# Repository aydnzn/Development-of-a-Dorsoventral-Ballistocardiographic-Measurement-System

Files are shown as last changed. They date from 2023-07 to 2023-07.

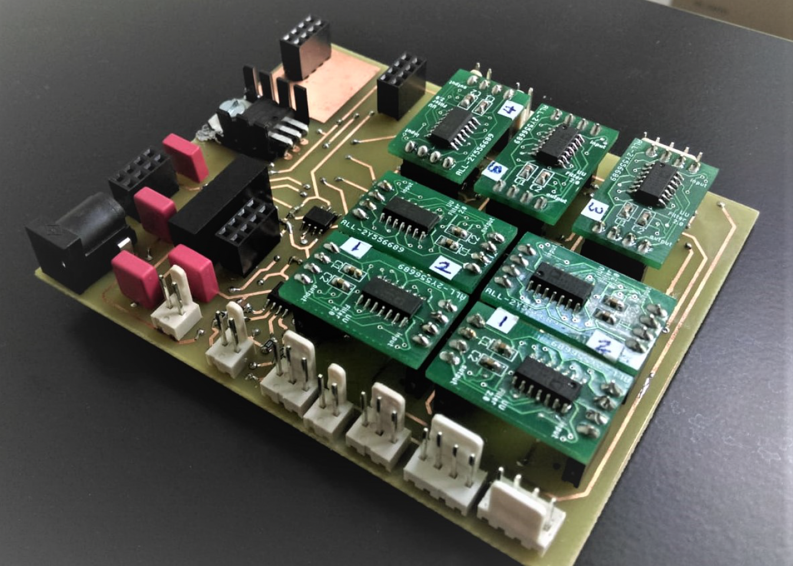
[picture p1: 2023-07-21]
photos/measurement_box_5.png

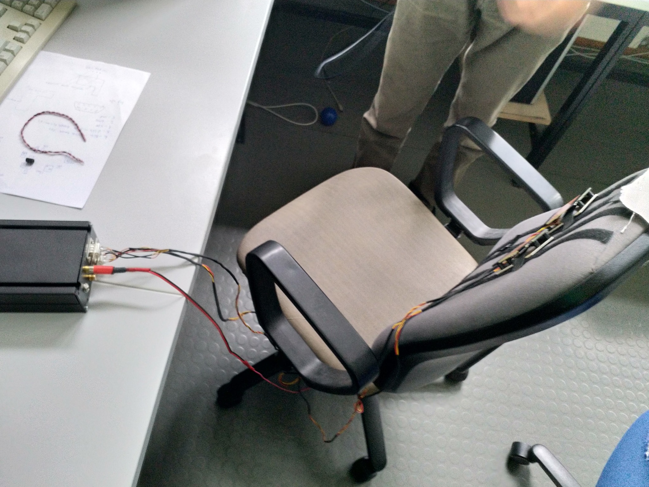
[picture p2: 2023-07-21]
photos/measurement_setup.jpeg

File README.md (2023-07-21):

# Internship Project: Development of a Dorsoventral Ballistocardiographic Measurement System

### Project Description
This project focuses on the development of a dorsoventral ballistocardiographic measurement system, specifically targeted at detecting ballistocardiographic impedance distortions in capacitive ECG. 

### Overview
This repository serves as the comprehensive archive of all the deliverables, artifacts, and insights gathered during my tenure as an intern at the [Medical Information Technology (MedIT), Helmholtz-Institute for Biomedical Engineering at RWTH Aachen University](https://www.medit.hia.rwth-aachen.de). The focus of my work centered around the design and development of capacitive ECG (cECG) and Ballistocardiography (BCG) systems, particularly exploring the nuances of human body's physiological vibrations and its impact on coupling impedance in cECG.

### Table of Contents
1. **Training_report.pdf** - This document encapsulates the cumulative learning and my detailed experience during the internship.
2. **./scripts** - This directory hosts all the Matlab scripts crafted for various analysis and computations.
3. **./photos** - A collection of photographs capturing significant moments and highlights of my internship journey.
4. **./figs** - This folder comprises of various visual representations, such as graphs and plots, created using Matlab for better understanding of problems, signals, and more.
5. **./data** - Preserved Matlab data files for future reference and use are stored here.
6. **./cnc_machine** - This section contains the necessary files required for operating the CNC machine which was instrumental in cutting the circuit boards.

### Contributors
This project was gracefully guided by [Mr. Uguz](https://ieeexplore.ieee.org/author/37086875617). I had the opportunity to develop the BCG measurement system, while my colleague, [Tuna](https://ieeexplore.ieee.org/author/37089188379), worked on the development of the impedance measurement system.

Our collaborative work, including my contributions, have been recognized and included in this [research paper](https://ieeexplore.ieee.org/document/8979354) authored by Mr. Uguz.

### License
This project is licensed under the terms of the MIT license.

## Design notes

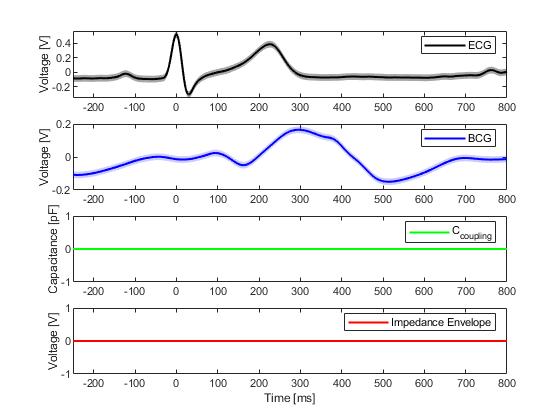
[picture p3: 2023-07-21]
figs/VM_right_2.0_rec60.jpg

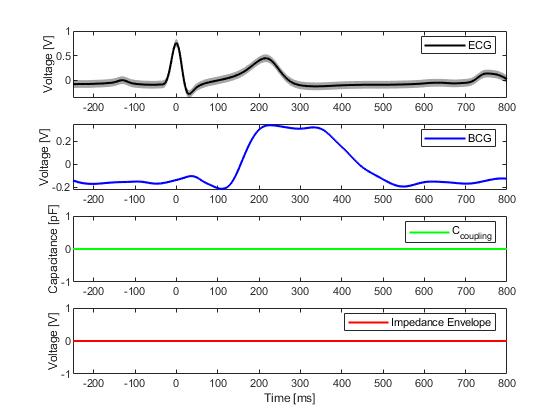
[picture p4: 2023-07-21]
figs/VM_left_6.0_rec54.jpg

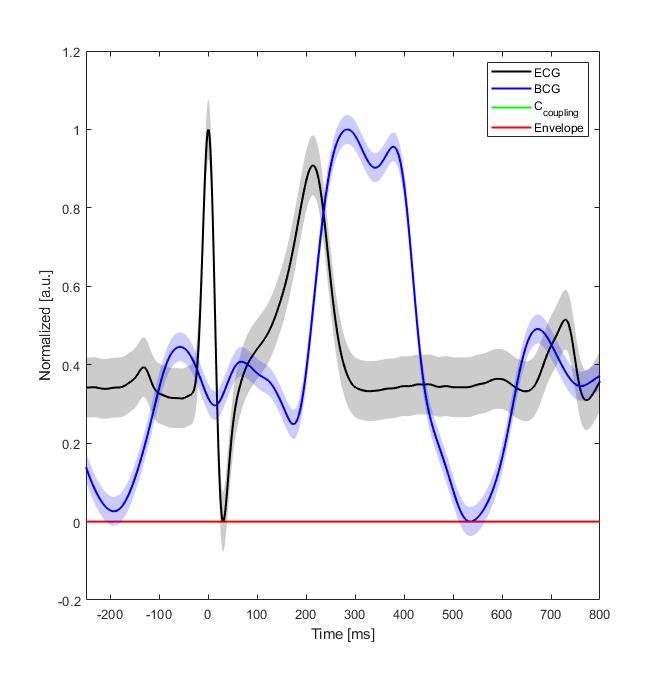
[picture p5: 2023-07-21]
figs/rec_48.jpg

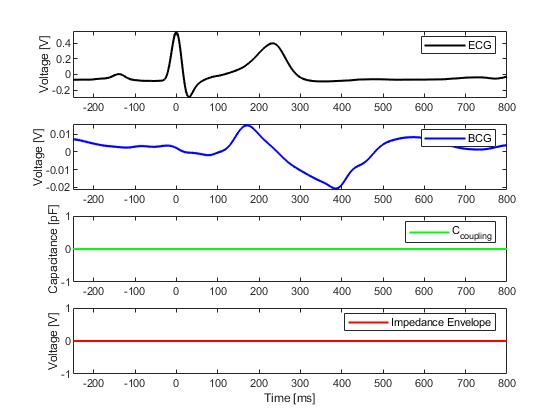
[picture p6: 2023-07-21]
figs/CM_right_1.0_rec65.jpg

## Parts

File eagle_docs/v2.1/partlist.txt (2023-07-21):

Partlist

Exported from v2.1.brd at 29.05.2019 11:04

EAGLE Version 9.1.2 Copyright (c) 1988-2018 Autodesk, Inc.

Assembly variant: 

Part     Value          Package          Library       Position (mm)         Orientation

BNC_ECG  1-227161-2     AMP_227161       con-coax      (7.4 12)              R90
BNC_RAW  1-227161-2     AMP_227161       con-coax      (7.5 48)              R90
BNC_RECT 1-227161-2     AMP_227161       con-coax      (7.5 30)              R90
BNC_REF  1-227161-2     AMP_227161       con-coax      (7.5 66)              R90
BP_RECT  FILTER_V2      MODULE_FILTER_V2 uguz_cEGG     (31 20)               R270
C1       22n            C0805            rcl           (51.6532 34.112)      MR0
C2       100n           C0805            resistor      (51.7 3.5)            MR270
C3       100n           C0805            resistor      (47.7 5.6)            MR90
C4       56n            C0805            rcl           (29.8 12.2)           MR0
C19      100n           C0805            resistor      (31.7332 35.9066)     MR0
C20      100n           C0805            resistor      (35.7104 53.9704)     MR0
D1       SD103          DIODE_SMB        eagle-ltspice (50.7 41.7)           MR0
HP       FILTER_V2      MODULE_FILTER_V2 uguz_cEGG     (31 56)               R270
IC1      OPA2107D       SO08             linear        (32.8104 44.586)      MR180
INA      AD8429         SO8              uguz_cEGG     (40.7 4)              MR90
JP_ECG                  1X02             pinhead       (23.2 3.8)            R90
JP_IMP                  1X04             pinhead       (27.0044 73.4384)     R0
JP_REF                  1X02             pinhead       (39.4356 73.8624)     R180
LP       FILTER_V2      MODULE_FILTER_V2 uguz_cEGG     (33.6 38)             R90
R1       72k            R0805            rcl           (51.7468 27.8732)     MR180
R2       1k             R0805            rcl           (52 53.2)             MR180
R3       100k           R0805            rcl           (52 48.2)             MR180
R4       82k            R0805            rcl           (31.8 16.7)           MR180
RG2      500            R0805            rcl           (31.8 4)              MR90
U$1      POWER_DUAL_12  MODULE_4X8       uguz_cEGG     (64.6424 41.005)      R270

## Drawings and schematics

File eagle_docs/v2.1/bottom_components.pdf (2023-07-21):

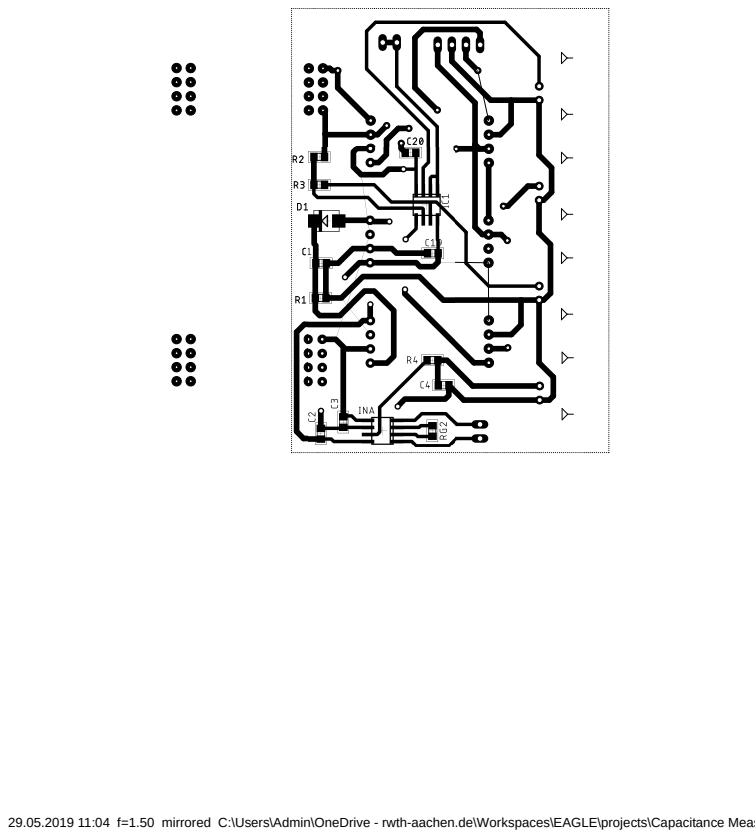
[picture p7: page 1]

29.05.2019 11:04 f=1.50 mirrored C:\Users\Admin\OneDrive - rwth-aachen.de\Workspaces\EAGLE\projects\Capacitance Measurement\Voltage_Divider\v2.1.brd

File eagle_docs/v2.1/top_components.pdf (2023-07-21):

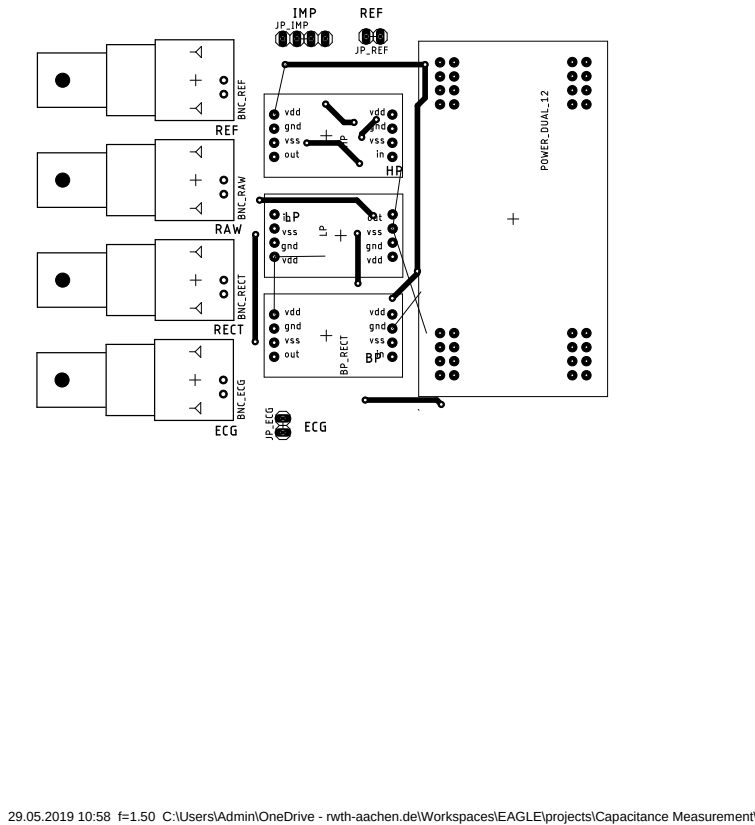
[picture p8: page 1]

29.05.2019 10:58 f=1.50 C:\Users\Admin\OneDrive - rwth-aachen.de\Workspaces\EAGLE\projects\Capacitance Measurement\Voltage_Divider\v2.1.brd

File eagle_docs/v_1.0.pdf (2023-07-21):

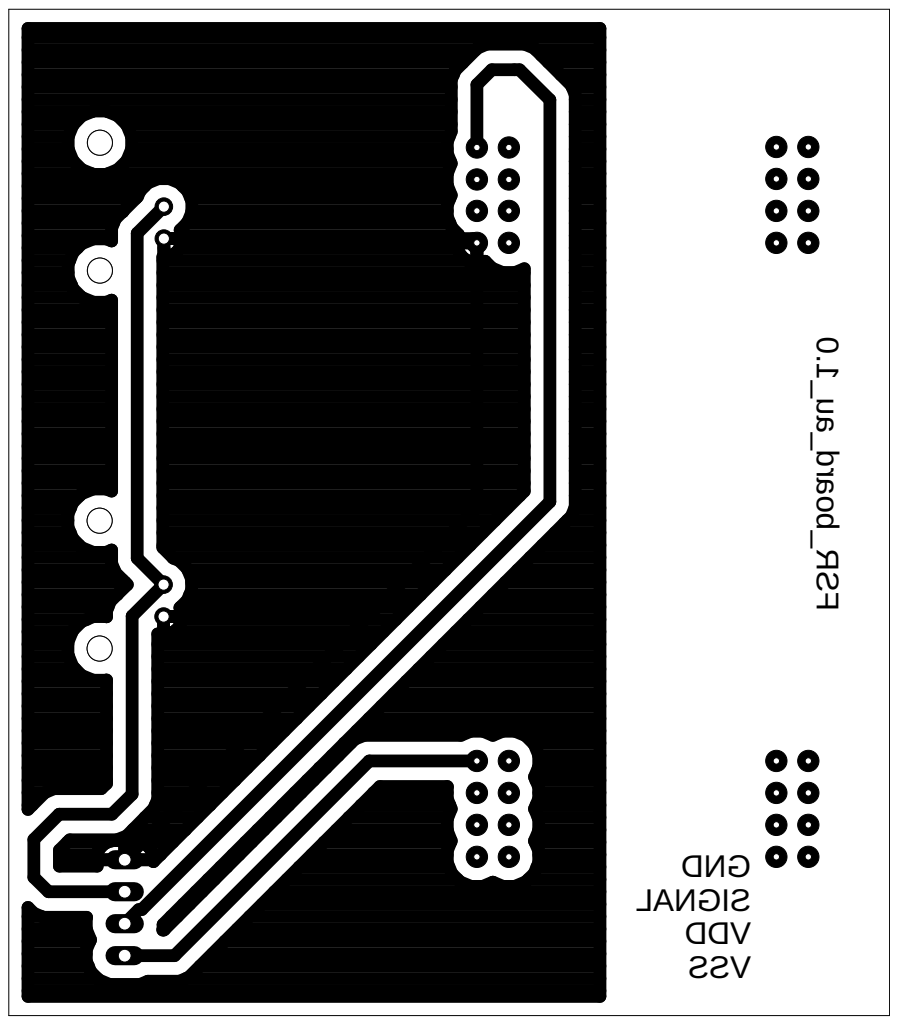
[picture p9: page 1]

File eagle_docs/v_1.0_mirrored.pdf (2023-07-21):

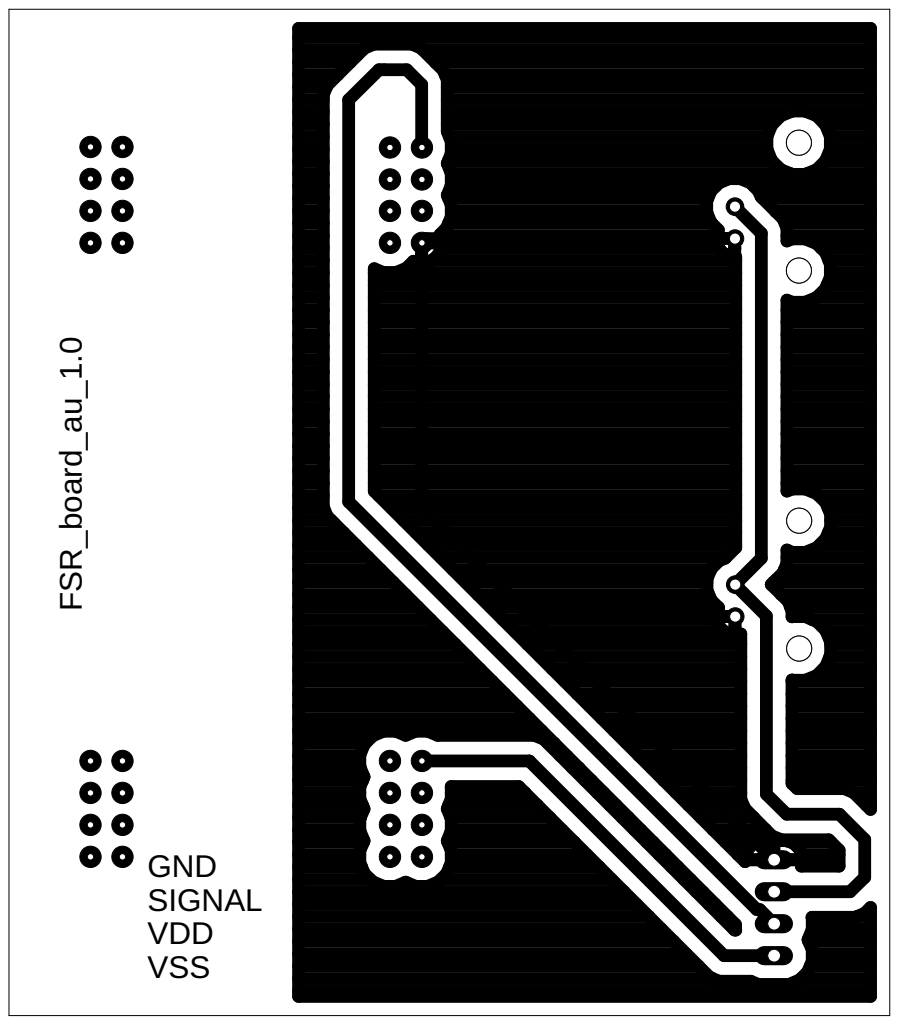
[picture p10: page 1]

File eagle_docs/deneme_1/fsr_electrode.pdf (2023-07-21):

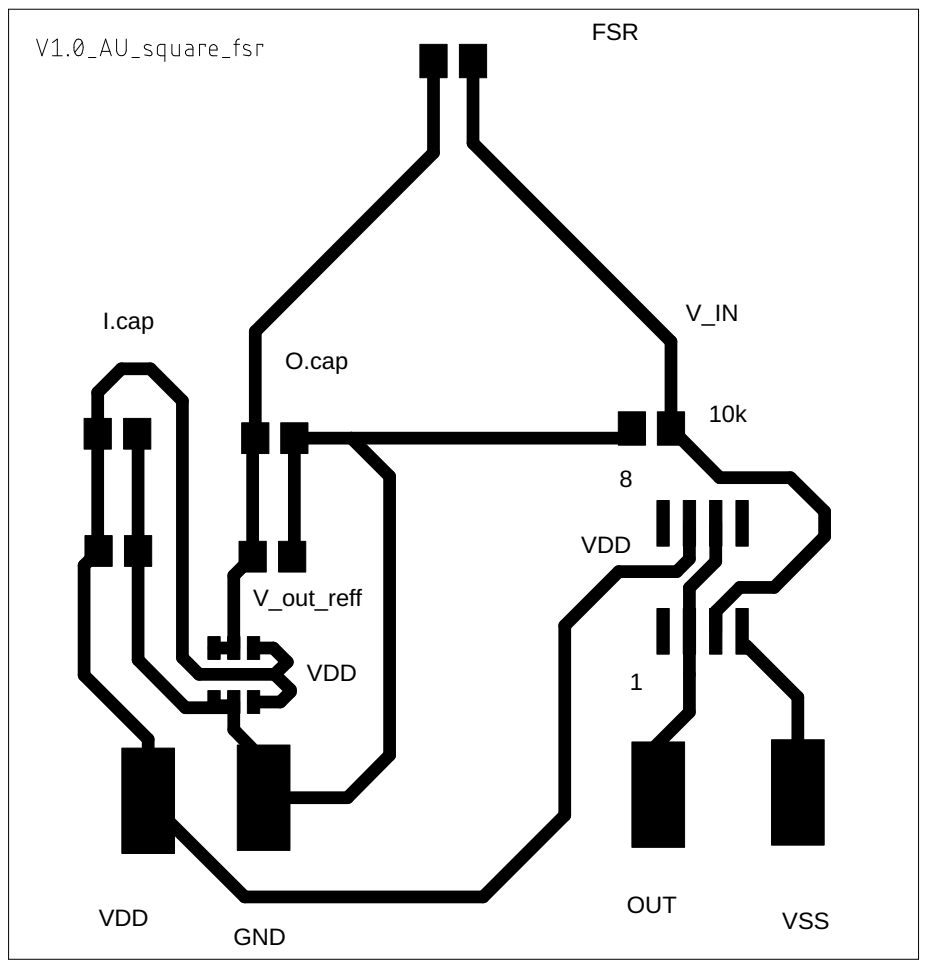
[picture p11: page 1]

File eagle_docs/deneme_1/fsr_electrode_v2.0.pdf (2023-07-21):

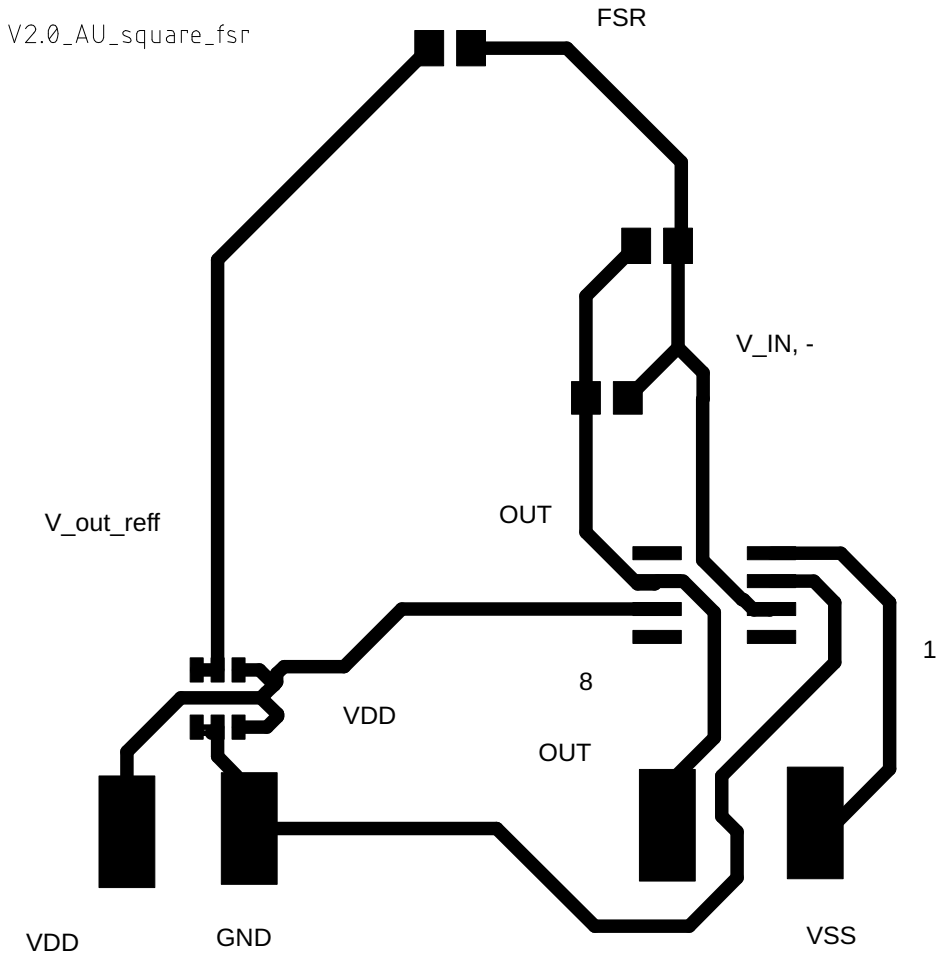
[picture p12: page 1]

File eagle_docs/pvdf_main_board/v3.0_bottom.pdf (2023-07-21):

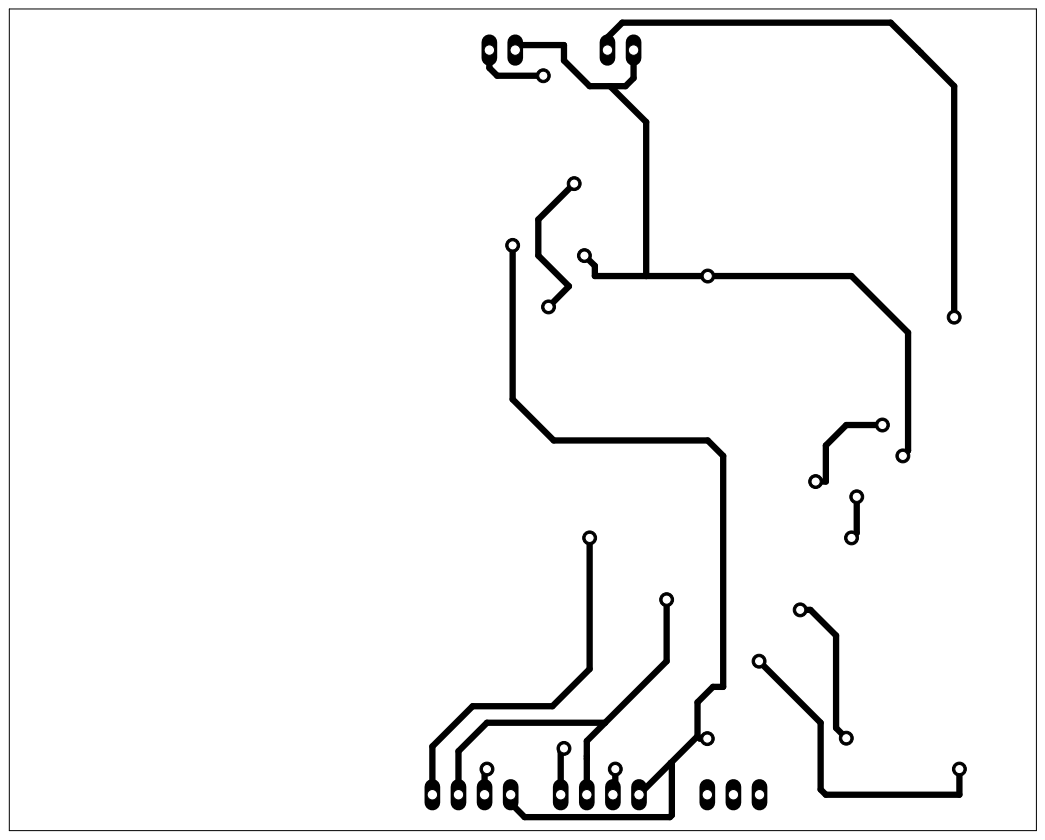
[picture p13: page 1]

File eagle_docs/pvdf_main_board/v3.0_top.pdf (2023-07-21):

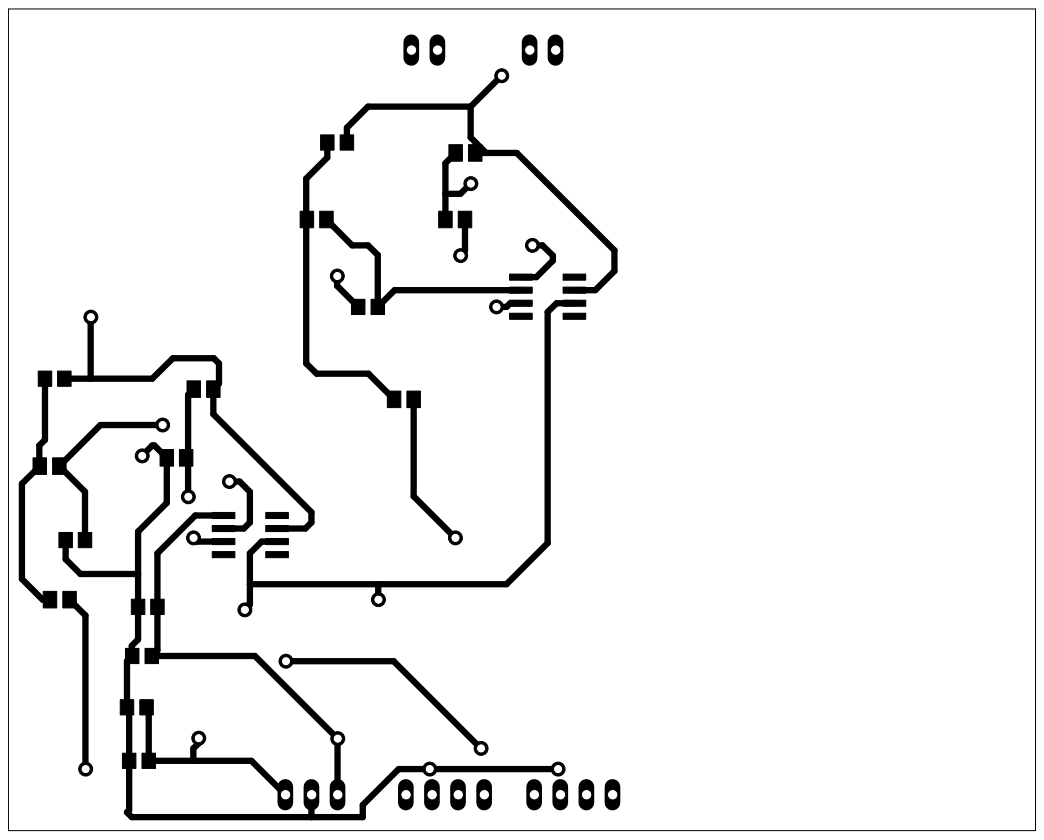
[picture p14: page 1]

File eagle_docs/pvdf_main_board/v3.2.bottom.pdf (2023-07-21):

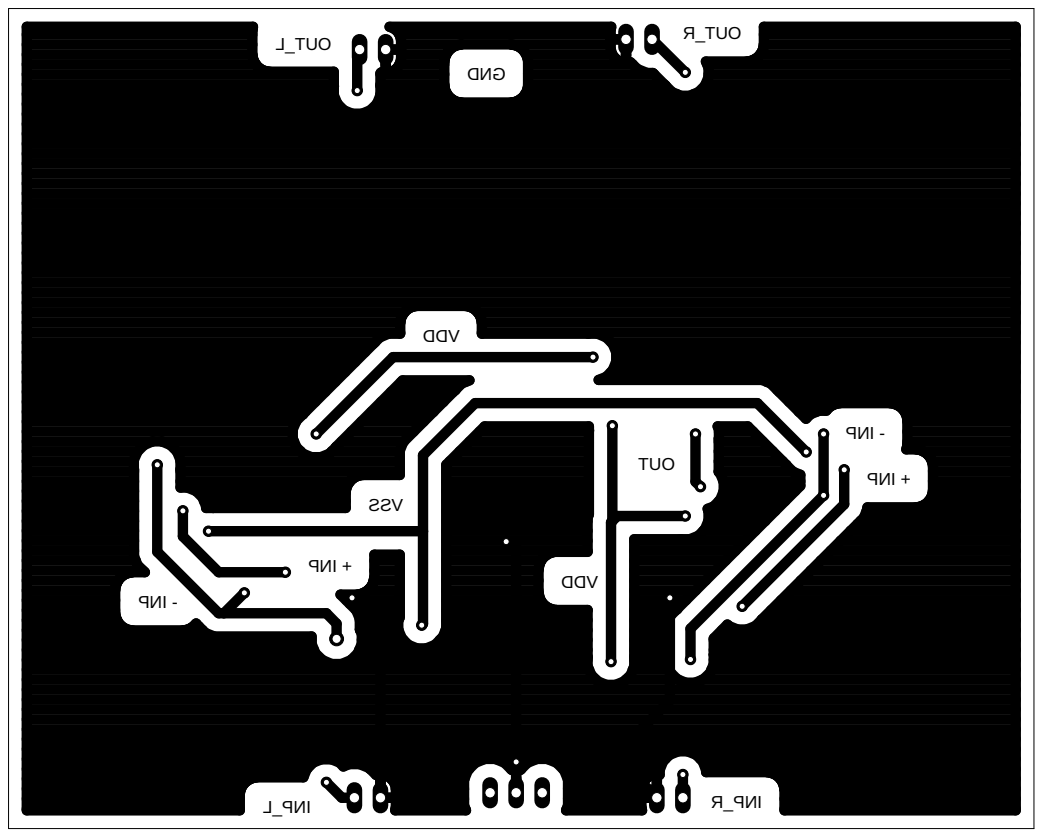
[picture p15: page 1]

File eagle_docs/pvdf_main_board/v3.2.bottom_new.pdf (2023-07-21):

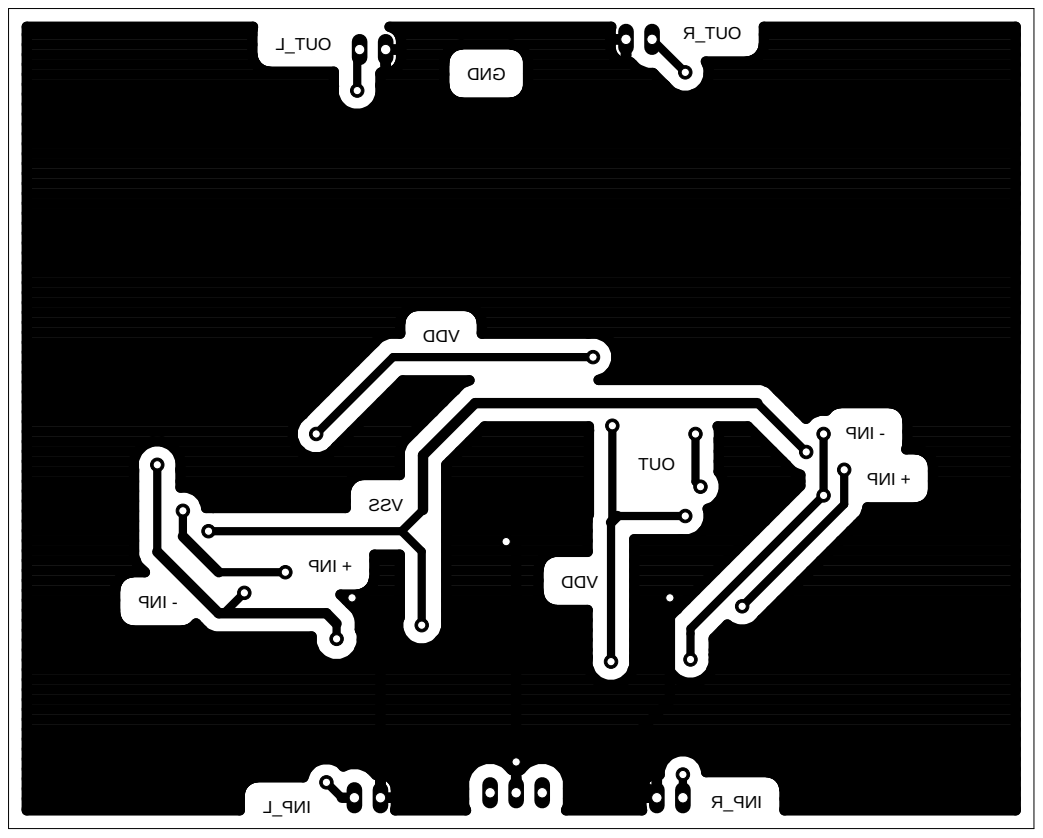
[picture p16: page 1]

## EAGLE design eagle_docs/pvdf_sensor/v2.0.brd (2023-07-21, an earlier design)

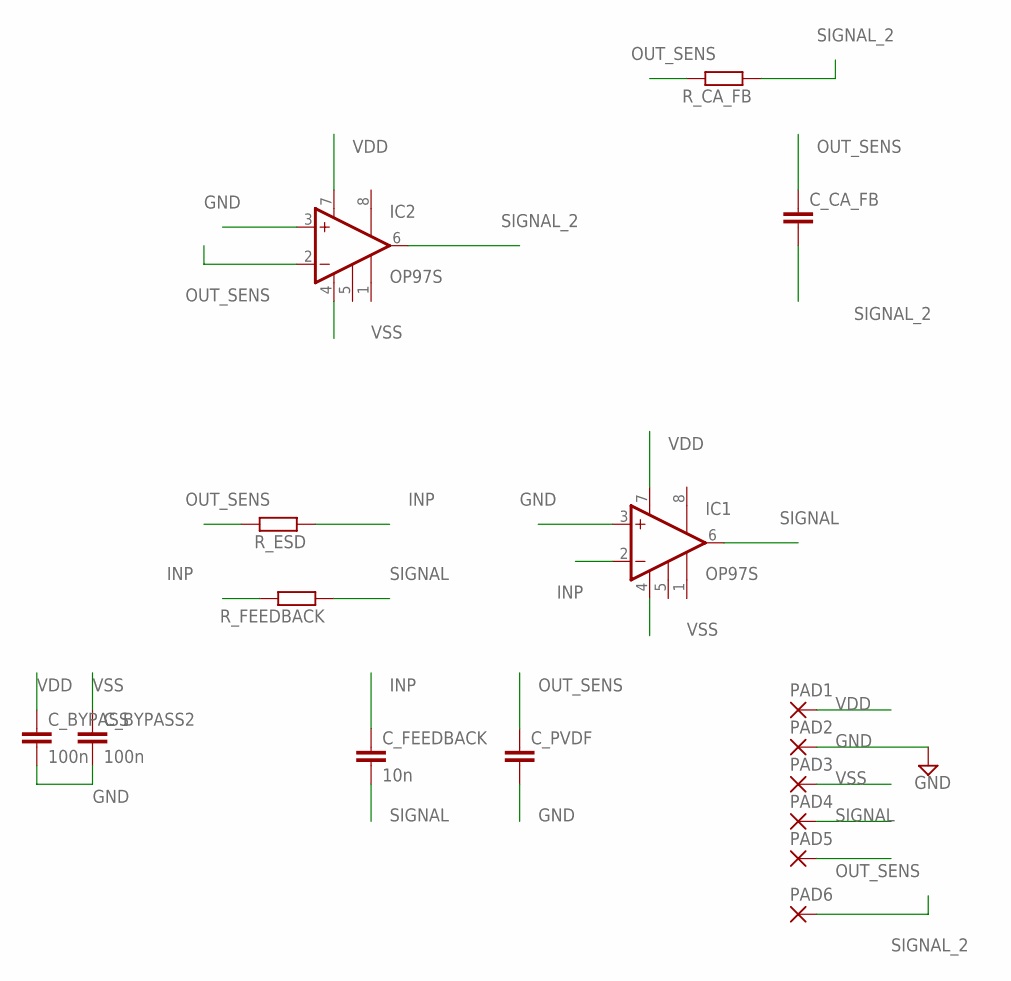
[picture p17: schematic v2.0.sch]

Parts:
C_BYPASS, C_BYPASS2: 100n; C0805
C_CA_FB: C-EUC0805; C0805
C_FEEDBACK: 10n; C0805
C_PVDF: C-EUC0805; C0805
IC1, IC2: OP97S; SO08
PAD1, PAD2, PAD3, PAD4, PAD5, PAD6: SMD5; SMD2,54-5,08
R_CA_FB: 10k; M0805
R_ESD: 5k; M0805
R_FEEDBACK: 100M; M0805

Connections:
GND: C_BYPASS.2, C_BYPASS2.2, C_PVDF.2, IC1.3 (+IN), IC2.3 (+IN), PAD2.1
INP: C_FEEDBACK.1, IC1.2 (-IN), R_ESD.1, R_FEEDBACK.2
OUT_SENS: C_CA_FB.1, C_PVDF.1, IC2.2 (-IN), PAD5.1, R_CA_FB.2, R_ESD.2
SIGNAL: C_FEEDBACK.2, IC1.6 (OUT), PAD4.1, R_FEEDBACK.1
SIGNAL_2: C_CA_FB.2, IC2.6 (OUT), PAD6.1, R_CA_FB.1
VDD: C_BYPASS.1, IC1.7 (V+), IC2.7 (V+), PAD1.1
VSS: C_BYPASS2.1, IC1.4 (V-), IC2.4 (V-), PAD3.1

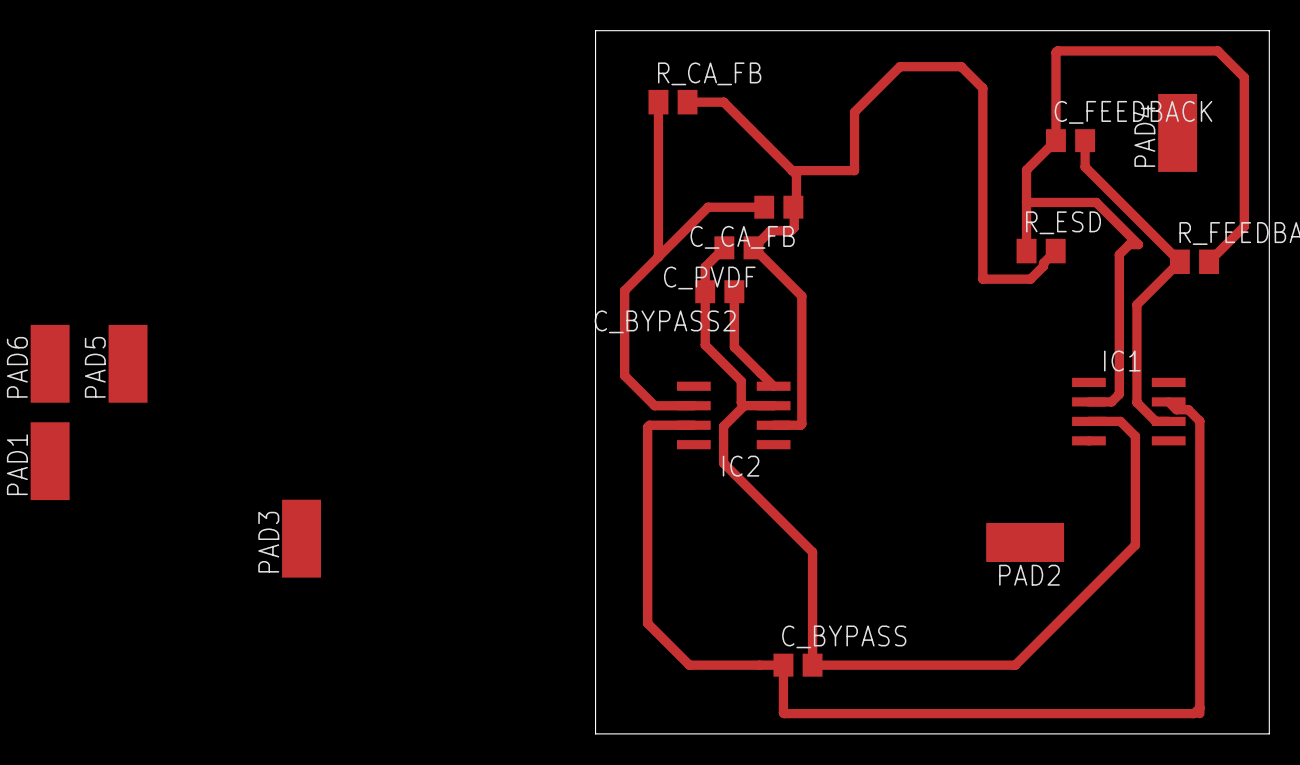
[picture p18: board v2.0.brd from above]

Board: 2 copper layers, 43.9 x 45.9 mm, 16 parts (0 on the bottom side), 7 nets.

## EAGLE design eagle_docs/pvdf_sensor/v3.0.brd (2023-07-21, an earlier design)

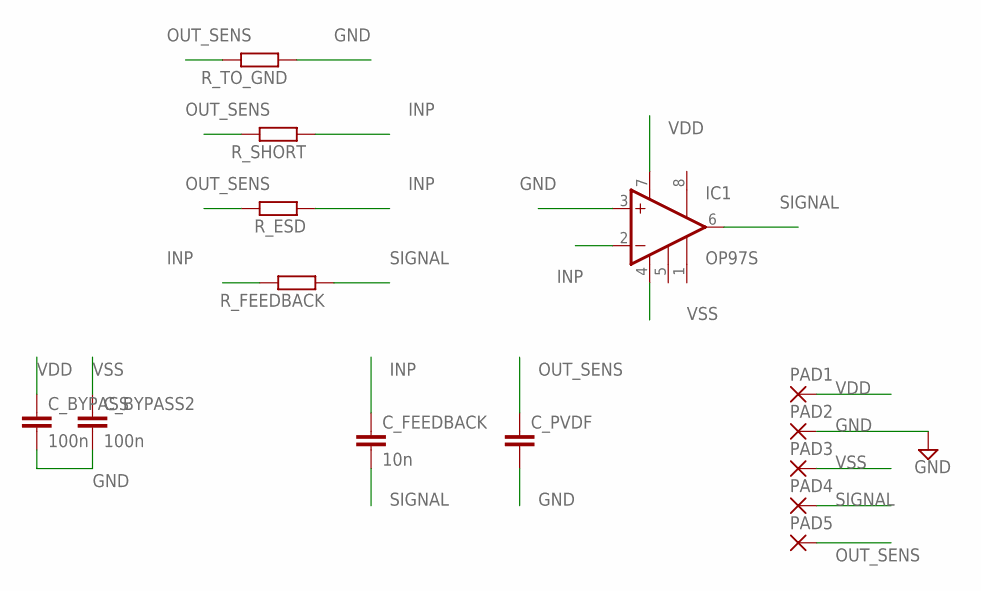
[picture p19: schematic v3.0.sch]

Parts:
C_BYPASS, C_BYPASS2: 100n; C0805
C_FEEDBACK: 10n; C0805
C_PVDF: C-EUC0805; C0805
IC1: OP97S; SO08
PAD1, PAD2, PAD3, PAD4, PAD5: SMD5; SMD2,54-5,08
R_ESD: 1M; M0805
R_FEEDBACK: 100M; M0805
R_SHORT: 1M; M0805
R_TO_GND: 1M; M0805

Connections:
GND: C_BYPASS.2, C_BYPASS2.2, C_PVDF.2, IC1.3 (+IN), PAD2.1, R_TO_GND.1
INP: C_FEEDBACK.1, IC1.2 (-IN), R_ESD.1, R_FEEDBACK.2, R_SHORT.1
OUT_SENS: C_PVDF.1, PAD5.1, R_ESD.2, R_SHORT.2, R_TO_GND.2
SIGNAL: C_FEEDBACK.2, IC1.6 (OUT), PAD4.1, R_FEEDBACK.1
VDD: C_BYPASS.1, IC1.7 (V+), PAD1.1
VSS: C_BYPASS2.1, IC1.4 (V-), PAD3.1

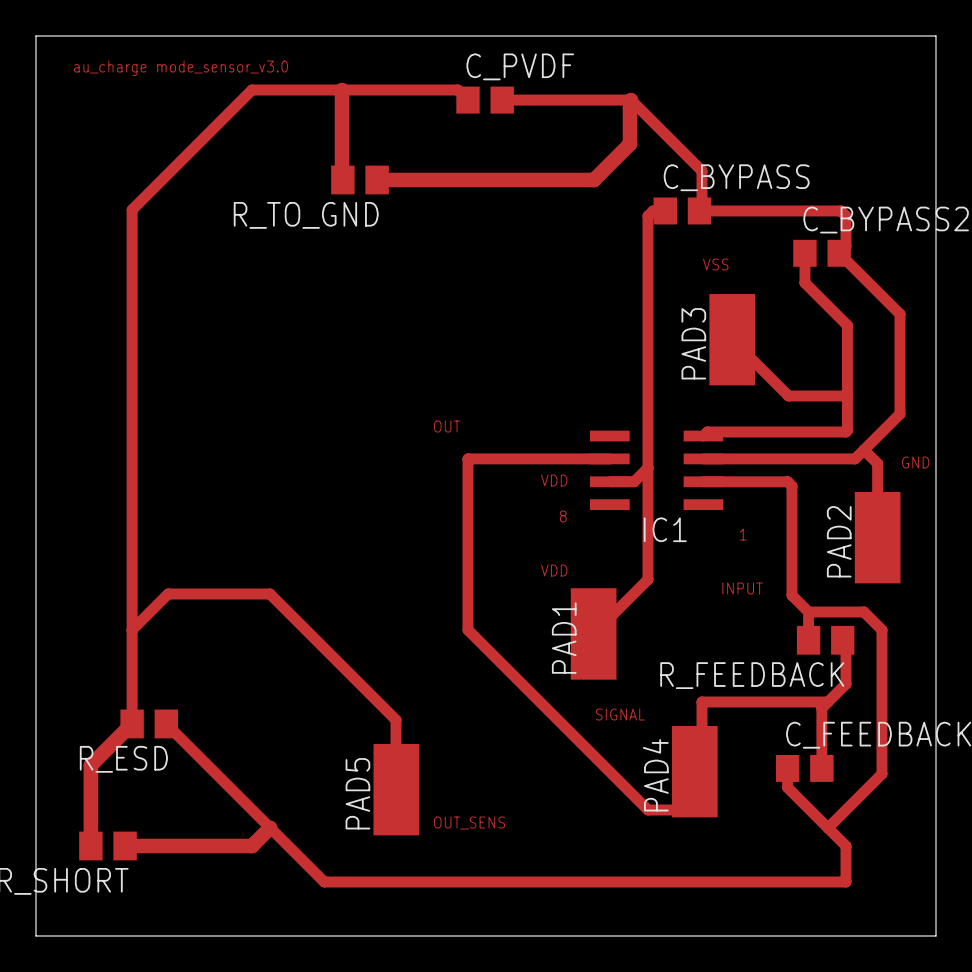
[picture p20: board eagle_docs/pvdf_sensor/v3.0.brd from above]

Board: 2 copper layers, 50.0 x 50.0 mm, 14 parts (0 on the bottom side), 6 nets.

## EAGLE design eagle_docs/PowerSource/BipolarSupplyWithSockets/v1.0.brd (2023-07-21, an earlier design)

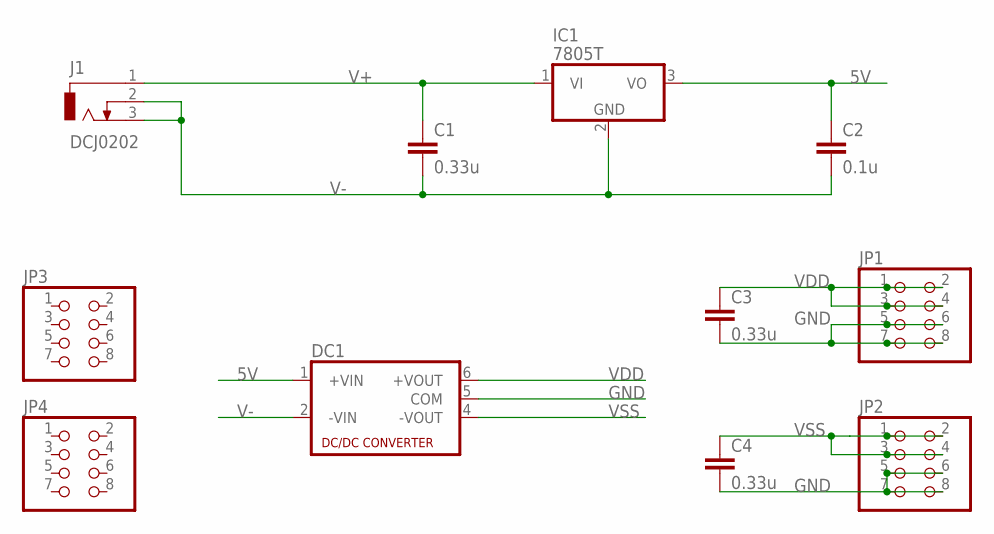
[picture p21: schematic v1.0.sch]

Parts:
C1, C3, C4: 0.33u; C050-045X075
C2: 0.1u; C050-045X075
DC1: NMA
IC1: 7805T; TO220H
J1: DCJ0202
JP1, JP2, JP3, JP4: PINHD-2X4; 2X04

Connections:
5V: C2.1, DC1.1 (+VIN), IC1.3 (VO)
GND: C3.2, C4.2, DC1.5 (COM), JP1.5, JP1.6, JP1.7, JP1.8, JP2.5, JP2.6, JP2.7, JP2.8
V+: C1.1, IC1.1 (VI), J1.1
V-: C1.2, C2.2, DC1.2 (-VIN), IC1.2 (GND), J1.2, J1.3
VDD: C3.1, DC1.6 (+VOUT), JP1.1, JP1.2, JP1.3, JP1.4
VSS: C4.1, DC1.4 (-VOUT), JP2.1, JP2.2, JP2.3, JP2.4

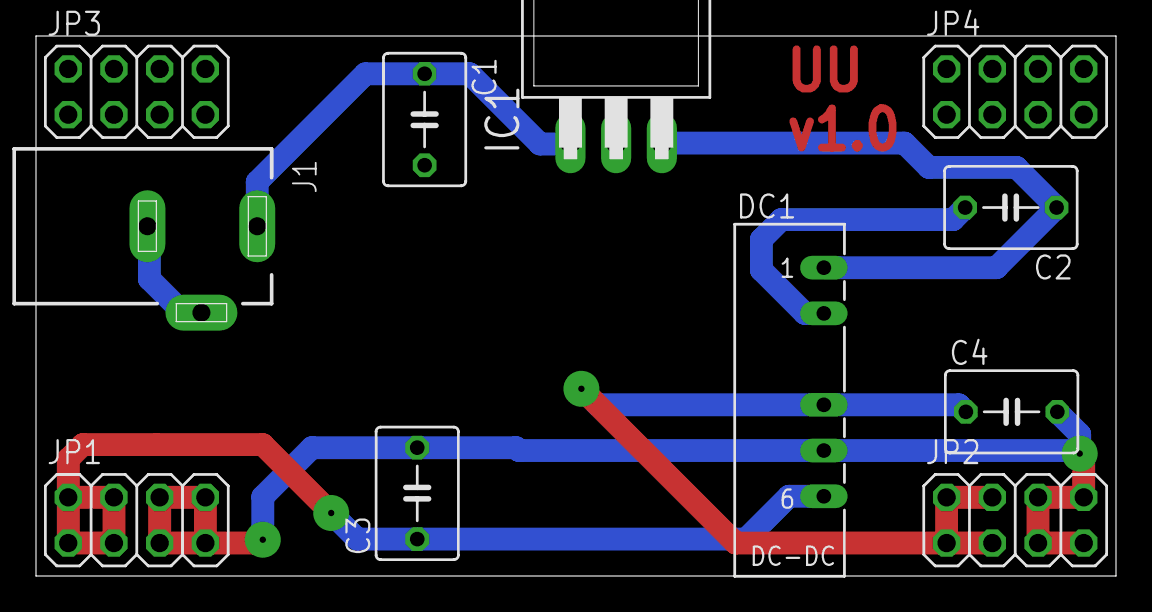
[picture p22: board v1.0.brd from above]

Board: 2 copper layers, 60.0 x 30.0 mm, 11 parts (0 on the bottom side), 6 nets.

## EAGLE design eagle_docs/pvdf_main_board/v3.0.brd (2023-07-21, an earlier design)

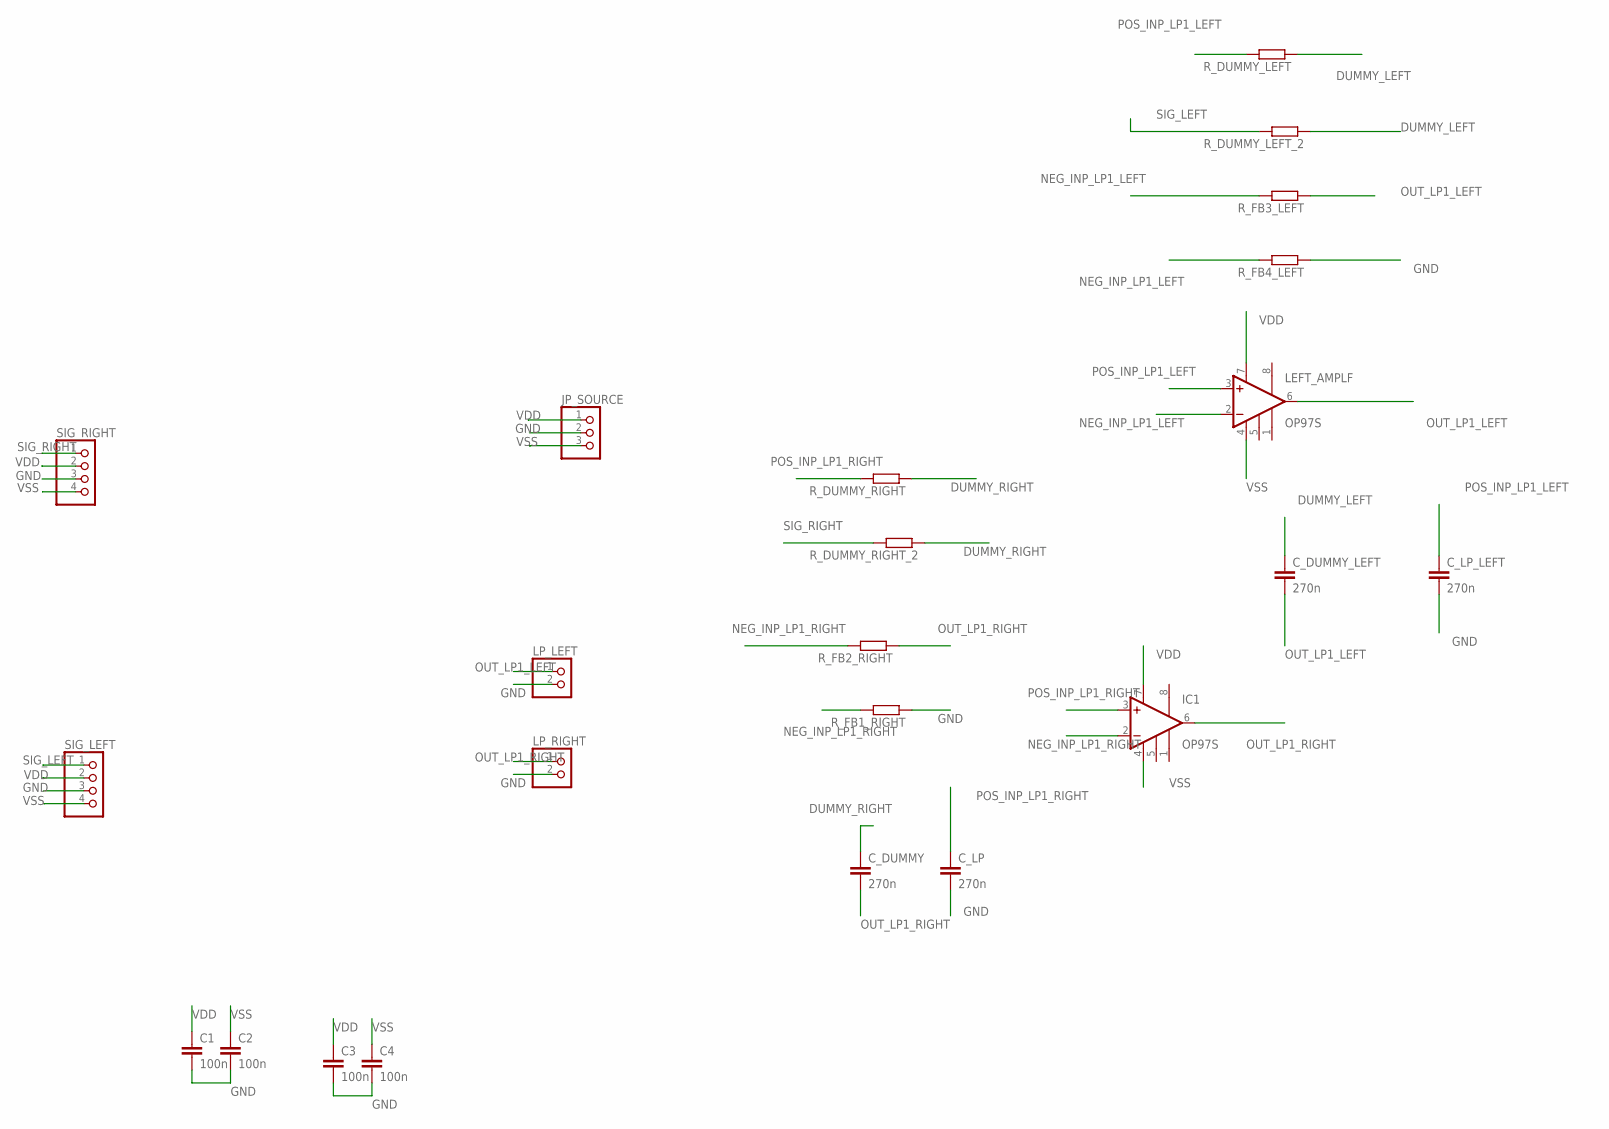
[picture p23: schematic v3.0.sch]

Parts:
C1, C2, C3, C4: 100n; C0805
C_DUMMY: 270n; C0805
C_DUMMY_LEFT: 270n; C0805
C_LP: 270n; C0805
C_LP_LEFT: 270n; C0805
IC1: OP97S; SO08
JP_SOURCE: PINHD-1X3; 1X03
LEFT_AMPLF: OP97S; SO08
LP_LEFT: PINHD-1X2; 1X02
LP_RIGHT: PINHD-1X2; 1X02
R_DUMMY_LEFT: 3.84k; M0805
R_DUMMY_LEFT_2: 3.84k; M0805
R_DUMMY_RIGHT: 3.84k; M0805
R_DUMMY_RIGHT_2: 3.84k; M0805
R_FB1_RIGHT, R_FB4_LEFT: 5.23k; M0805
R_FB2_RIGHT, R_FB3_LEFT: 256k; M0805
SIG_LEFT: PINHD-1X4; 1X04
SIG_RIGHT: PINHD-1X4; 1X04

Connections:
DUMMY_LEFT: C_DUMMY_LEFT.1, R_DUMMY_LEFT.1, R_DUMMY_LEFT_2.1
DUMMY_RIGHT: C_DUMMY.1, R_DUMMY_RIGHT.1, R_DUMMY_RIGHT_2.1
GND: C1.2, C2.2, C3.2, C4.2, C_LP.2, C_LP_LEFT.2, JP_SOURCE.2, LP_LEFT.2, LP_RIGHT.2, R_FB1_RIGHT.1, R_FB4_LEFT.1, SIG_LEFT.3, SIG_RIGHT.3
NEG_INP_LP1_LEFT: LEFT_AMPLF.2 (-IN), R_FB3_LEFT.2, R_FB4_LEFT.2
NEG_INP_LP1_RIGHT: IC1.2 (-IN), R_FB1_RIGHT.2, R_FB2_RIGHT.2
OUT_LP1_LEFT: C_DUMMY_LEFT.2, LEFT_AMPLF.6 (OUT), LP_LEFT.1, R_FB3_LEFT.1
OUT_LP1_RIGHT: C_DUMMY.2, IC1.6 (OUT), LP_RIGHT.1, R_FB2_RIGHT.1
POS_INP_LP1_LEFT: C_LP_LEFT.1, LEFT_AMPLF.3 (+IN), R_DUMMY_LEFT.2
POS_INP_LP1_RIGHT: C_LP.1, IC1.3 (+IN), R_DUMMY_RIGHT.2
SIG_LEFT: R_DUMMY_LEFT_2.2, SIG_LEFT.1
SIG_RIGHT: R_DUMMY_RIGHT_2.2, SIG_RIGHT.1
VDD: C1.1, C3.1, IC1.7 (V+), JP_SOURCE.1, LEFT_AMPLF.7 (V+), SIG_LEFT.2, SIG_RIGHT.2
VSS: C2.1, C4.1, IC1.4 (V-), JP_SOURCE.3, LEFT_AMPLF.4 (V-), SIG_LEFT.4, SIG_RIGHT.4

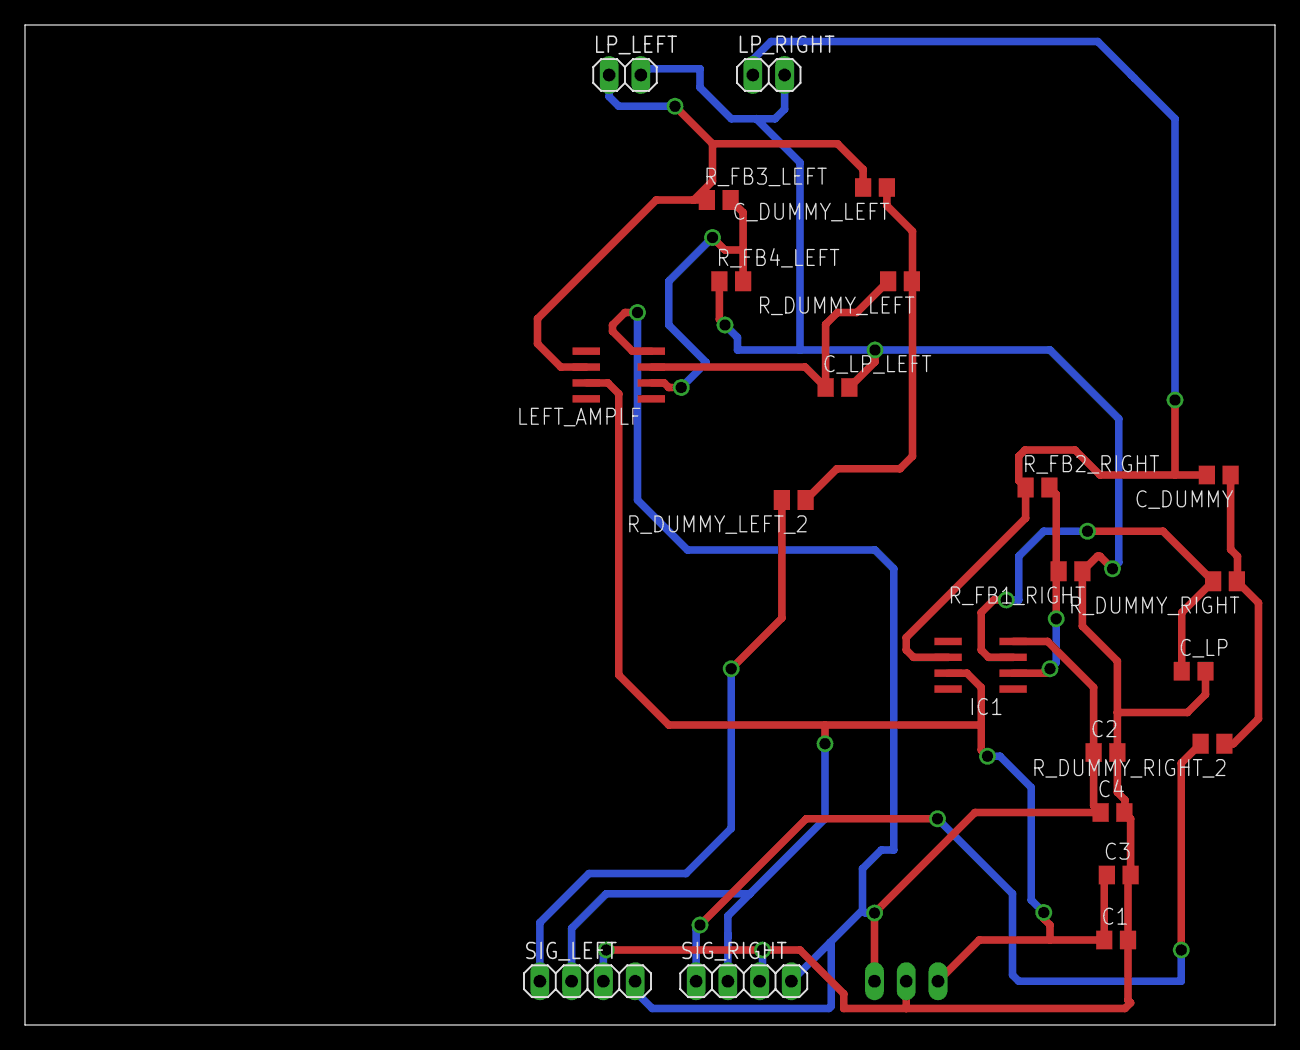
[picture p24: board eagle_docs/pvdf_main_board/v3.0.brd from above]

Board: 2 copper layers, 100.0 x 80.0 mm, 23 parts (1 on the bottom side), 13 nets.

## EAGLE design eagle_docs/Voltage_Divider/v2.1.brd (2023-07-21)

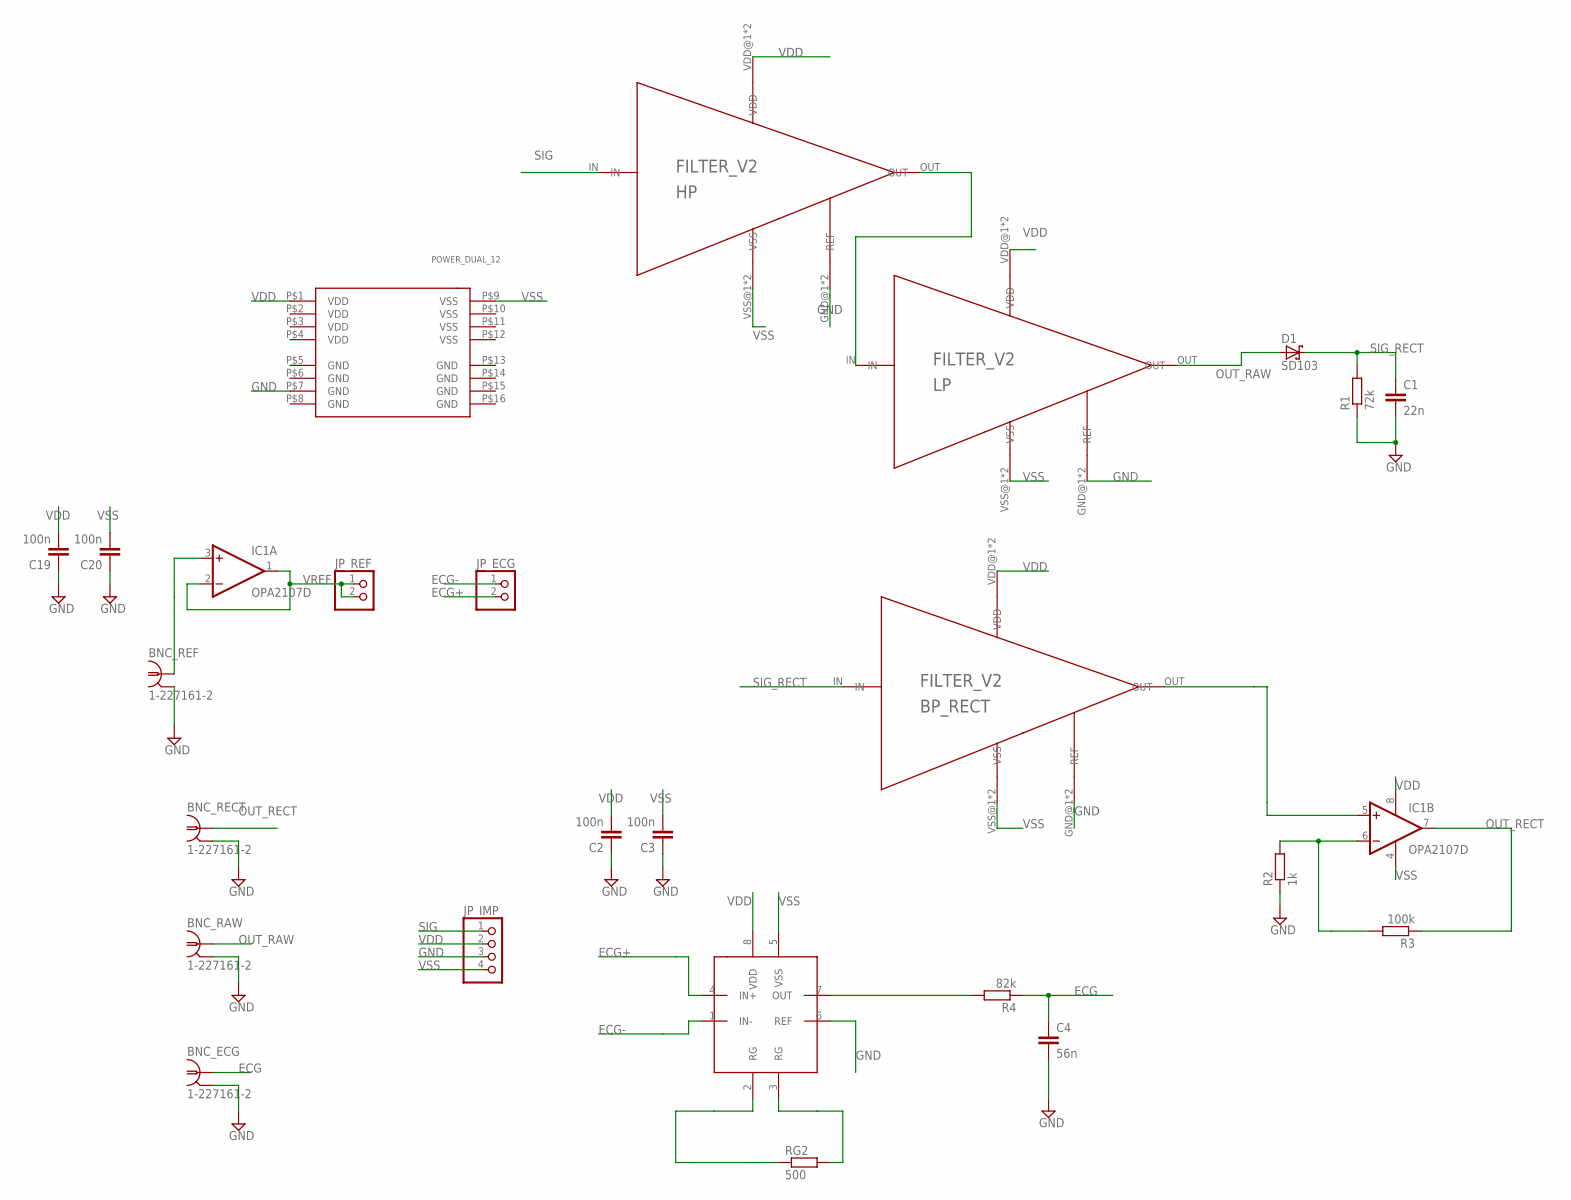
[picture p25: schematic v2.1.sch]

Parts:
BNC_ECG: 1-227161-2; AMP_227161
BNC_RAW: 1-227161-2; AMP_227161
BNC_RECT: 1-227161-2; AMP_227161
BNC_REF: 1-227161-2; AMP_227161
BP_RECT: FILTER_V2; MODULE_FILTER_V2
C1: 22n; C0805
C2, C3, C19, C20: 100n; C0805
C4: 56n; C0805
D1: SD103; DIODE_SMB
HP: FILTER_V2; MODULE_FILTER_V2
IC1: OPA2107D; SO08
INA: AD8429; SO8
JP_ECG: PINHD-1X2; 1X02
JP_IMP: PINHD-1X4; 1X04
JP_REF: PINHD-1X2; 1X02
LP: FILTER_V2; MODULE_FILTER_V2
R1: 72k; R0805
R2: 1k; R0805
R3: 100k; R0805
R4: 82k; R0805
RG2: 500; R0805
U$1: POWER_DUAL_12; MODULE_4X8

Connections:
ECG: BNC_ECG.1, C4.1, R4.1
ECG+: INA.4 (IN+), JP_ECG.2
ECG-: INA.1 (IN-), JP_ECG.1
GND: BNC_ECG.2, BNC_RAW.2, BNC_RECT.2, BNC_REF.2, BP_RECT.GND@1 (REF), BP_RECT.GND@2 (REF), C1.2, C2.1, C3.1, C4.2, C19.1, C20.1, HP.GND@1 (REF), HP.GND@2 (REF), INA.6 (REF), JP_IMP.3, LP.GND@1 (REF), LP.GND@2 (REF), R1.1, R2.1, U$1.P$7 (GND)
unnamed: IC1.6 (-IN), R2.2, R3.2
unnamed: BP_RECT.OUT, IC1.5 (+IN)
unnamed: INA.7 (OUT), R4.2
unnamed: HP.OUT, LP.IN
unnamed: BNC_REF.1, IC1.3 (+IN)
unnamed: INA.2 (RG), RG2.1
unnamed: INA.3 (RG), RG2.2
OUT_RAW: BNC_RAW.1, D1.A (C), LP.OUT
OUT_RECT: BNC_RECT.1, IC1.7 (OUT), R3.1
SIG: HP.IN, JP_IMP.1
SIG_RECT: BP_RECT.IN, C1.1, D1.C (A), R1.2
VDD: BP_RECT.VDD@1 (VDD), BP_RECT.VDD@2 (VDD), C2.2, C19.2, HP.VDD@1 (VDD), HP.VDD@2 (VDD), IC1.8 (V+), INA.8 (VDD), JP_IMP.2, LP.VDD@1 (VDD), LP.VDD@2 (VDD), U$1.P$1 (VDD)
VREF: IC1.1 (OUT), IC1.2 (-IN), JP_REF.1, JP_REF.2
VSS: BP_RECT.VSS@1 (VSS), BP_RECT.VSS@2 (VSS), C3.2, C20.2, HP.VSS@1 (VSS), HP.VSS@2 (VSS), IC1.4 (V-), INA.5 (VSS), JP_IMP.4, LP.VSS@1 (VSS), LP.VSS@2 (VSS), U$1.P$9 (VSS)

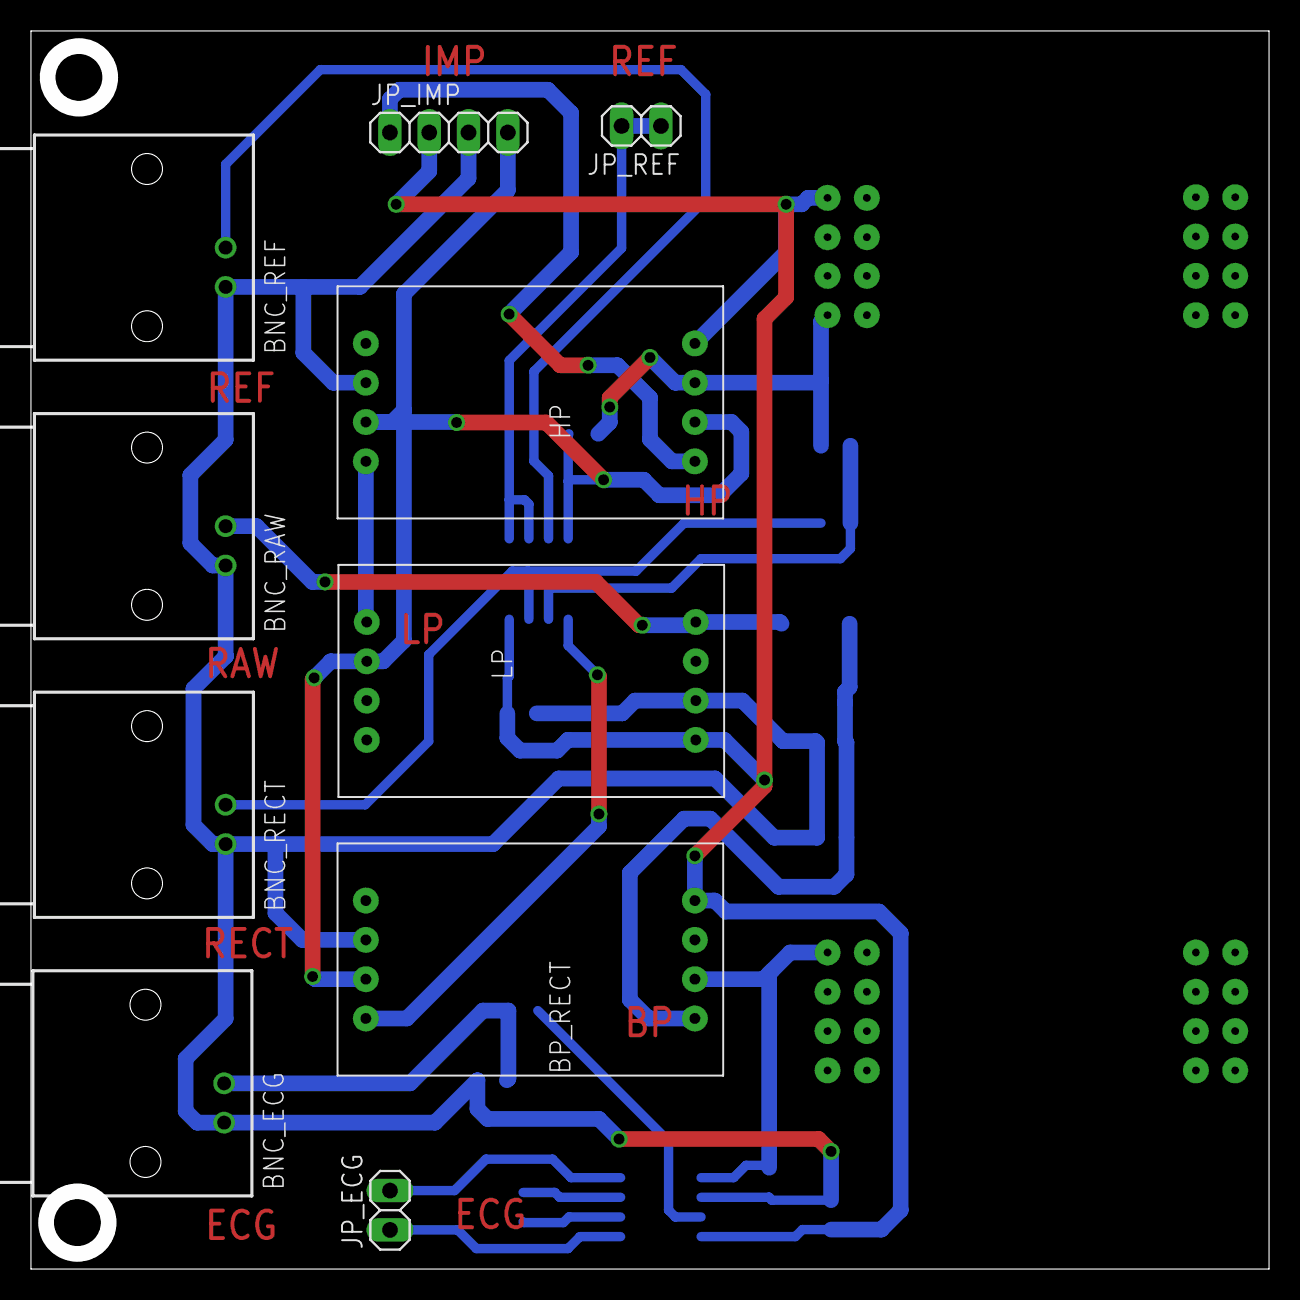
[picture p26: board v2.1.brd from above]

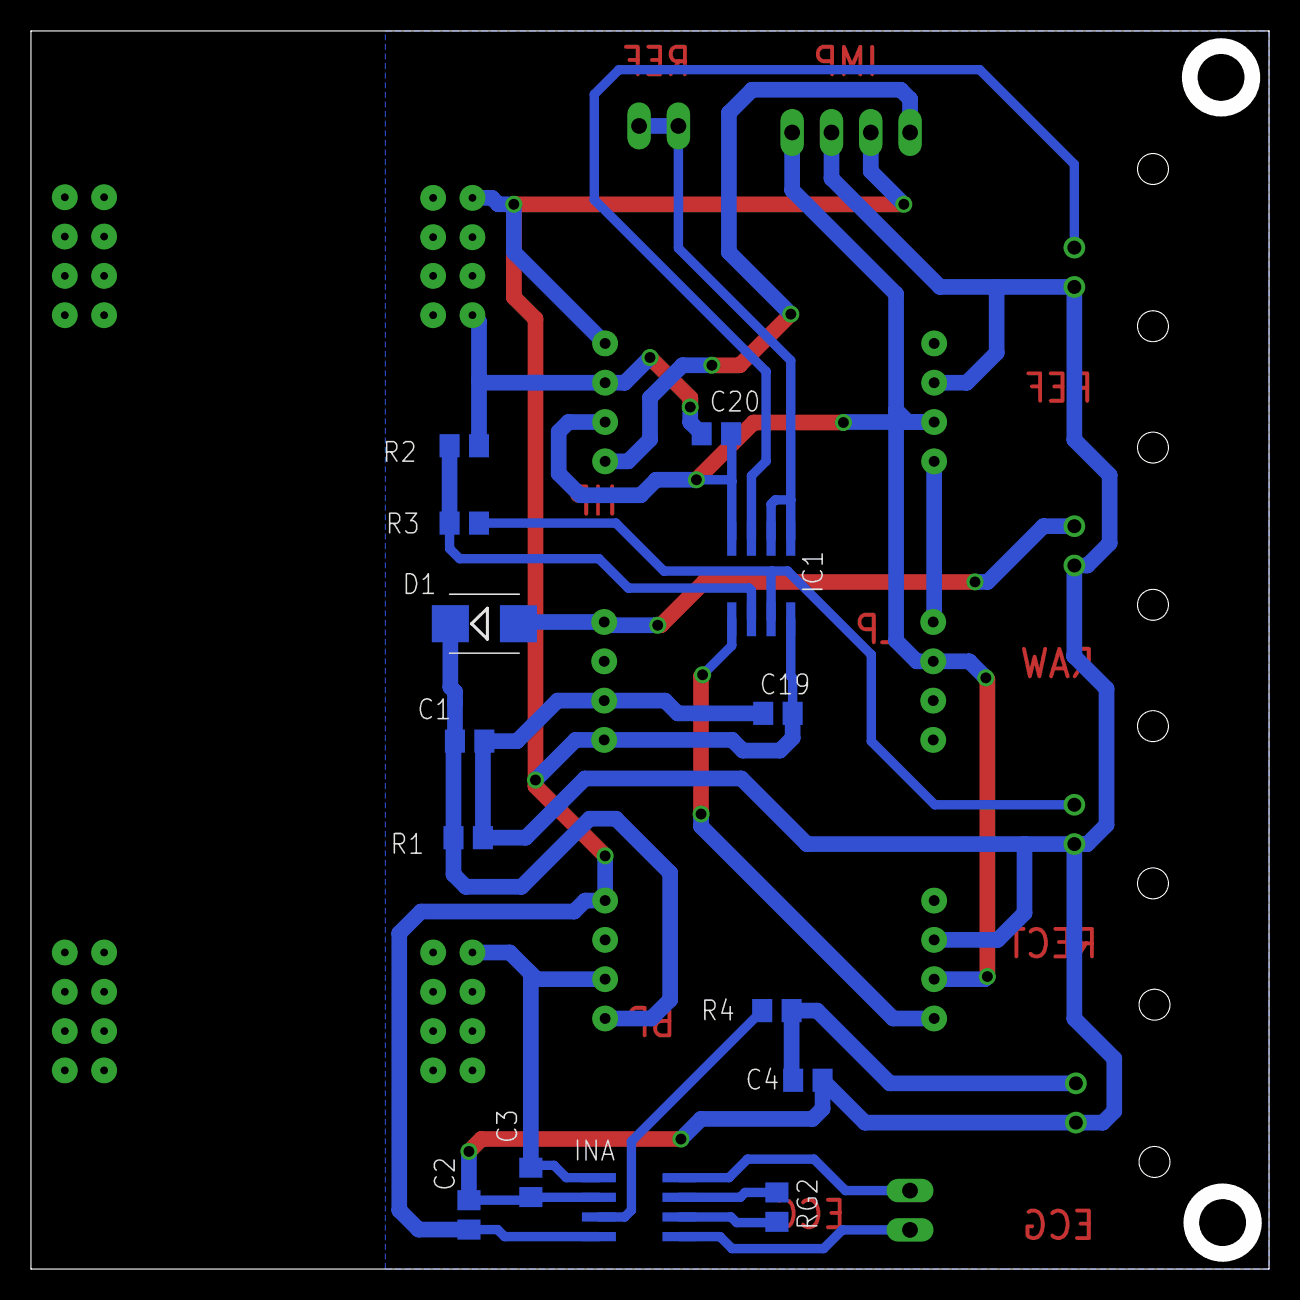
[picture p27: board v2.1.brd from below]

Board: 2 copper layers, 80.0 x 80.0 mm, 25 parts (14 on the bottom side), 18 nets.

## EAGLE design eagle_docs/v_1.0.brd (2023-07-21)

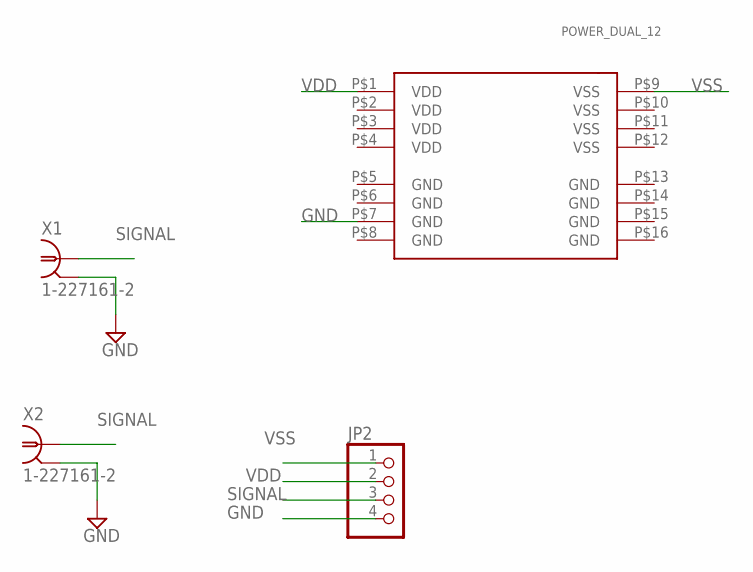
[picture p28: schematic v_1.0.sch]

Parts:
JP2: PINHD-1X4; 1X04
U$1: POWER_DUAL_12; MODULE_4X8
X1, X2: 1-227161-2; AMP_227161

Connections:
GND: JP2.4, U$1.P$7 (GND), X1.2, X2.2
SIGNAL: JP2.3, X1.1, X2.1
VDD: JP2.2, U$1.P$1 (VDD)
VSS: JP2.1, U$1.P$9 (VSS)


Board: 2 copper layers, 70.0 x 80.0 mm, 4 parts (0 on the bottom side), 4 nets.

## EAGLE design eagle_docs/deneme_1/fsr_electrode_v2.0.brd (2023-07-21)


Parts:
C1, C2: 1u; C0805
C2_CERAMIC: 10u; C0805
C2_CERAMIC1, C3_CERAMIC: 0.1u; C0805
C_BYPASS, C_BYPASS2: 100n; C0805
IC1: OP97S; SO08
PAD1, PAD2, PAD3, PAD4: SMD5; SMD2,54-5,08
REF3450: REF3450IDBVR; UZUN
R_REF1, R_REF2: 10k; M0805

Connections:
GND: C2.2, C2_CERAMIC.2, C2_CERAMIC1.2, C3_CERAMIC.2, C_BYPASS.2, C_BYPASS2.2, IC1.3 (+IN), PAD2.1, REF3450.P$1 (GND_F), REF3450.P$2 (GND_S)
OUT_REF: C2_CERAMIC.1, C2_CERAMIC1.1, REF3450.P$5 (OUT_S), REF3450.P$6 (OUT_F), R_REF1.2
SIGNAL: C1.2, IC1.6 (OUT), PAD4.1, R_REF2.1
VDD: C2.1, C3_CERAMIC.1, C_BYPASS.1, IC1.7 (V+), PAD1.1, REF3450.P$3 (ENABLE), REF3450.P$4 (IN)
VSS: C_BYPASS2.1, IC1.4 (V-), PAD3.1
V_IN: C1.1, IC1.2 (-IN), R_REF1.1, R_REF2.2

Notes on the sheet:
V.1.0
Vref+0.05 - 13
-0.3 - IN+0.3
Vreff -0.3V - 5.5V


Board: 2 copper layers, 43.9 x 45.9 mm, 15 parts (0 on the bottom side), 6 nets.

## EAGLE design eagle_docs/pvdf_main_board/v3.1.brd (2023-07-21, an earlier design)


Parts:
C1, C2: 100n; C0805
C3, C4: 10u; C0805
C_DUMMY_LEFT: 100n; C0805
C_DUMMY_RIGHT: 100n; C0805
C_LP_LEFT: 10n; C0805
C_LP_RIGHT: 10n; C0805
FILTER_GAIN_STAGE_LEFT: ADA4004-2ARZ; SOIC127P600X175-8N
FILTER_GAIN_STAGE_RIGHT: ADA4004-2ARZ; SOIC127P600X175-8N
JP_SOURCE: PINHD-1X3; 1X03
LP_LEFT: PINHD-1X2; 1X02
LP_RIGHT: PINHD-1X2; 1X02
R2_LEFT, R2_RIGHT: 6.8k; M0805
RF_LEFT: 330k; M0805
RF_RIGHT: 330k; M0805
R_DUMMY_LEFT: 1M; M0805
R_DUMMY_LEFT_2: 68k; M0805
R_DUMMY_RIGHT: 1M; M0805
R_DUMMY_RIGHT_2: 68k; M0805
SIG_LEFT: PINHD-1X2; 1X02
SIG_RIGHT: PINHD-1X2; 1X02

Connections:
DUMMY_LEFT: C_DUMMY_LEFT.1, R_DUMMY_LEFT.1, R_DUMMY_LEFT_2.1
DUMMY_RIGHT: C_DUMMY_RIGHT.1, R_DUMMY_RIGHT.1, R_DUMMY_RIGHT_2.1
GND: C1.2, C2.2, C3.2, C4.2, C_LP_LEFT.2, C_LP_RIGHT.2, JP_SOURCE.2, LP_LEFT.2, LP_RIGHT.2, R2_LEFT.1, R2_RIGHT.1, SIG_LEFT.2, SIG_RIGHT.2
NEG_INP_NONINV_AMP_LEFT: FILTER_GAIN_STAGE_LEFT.6 (INB-), R2_LEFT.2, RF_LEFT.1
NEG_INP_NONINV_AMP_RIGHT: FILTER_GAIN_STAGE_RIGHT.6 (INB-), R2_RIGHT.2, RF_RIGHT.1
OUT_LP1_LEFT: C_DUMMY_LEFT.2, FILTER_GAIN_STAGE_LEFT.1 (OUTA), FILTER_GAIN_STAGE_LEFT.2 (INA-), FILTER_GAIN_STAGE_LEFT.5 (INB+)
OUT_LP1_RIGHT: C_DUMMY_RIGHT.2, FILTER_GAIN_STAGE_RIGHT.1 (OUTA), FILTER_GAIN_STAGE_RIGHT.2 (INA-), FILTER_GAIN_STAGE_RIGHT.5 (INB+)
OUT_NONINV_AMP_LEFT: FILTER_GAIN_STAGE_LEFT.7 (OUTB), LP_LEFT.1, RF_LEFT.2
OUT_NONINV_AMP_RIGHT: FILTER_GAIN_STAGE_RIGHT.7 (OUTB), LP_RIGHT.1, RF_RIGHT.2
POS_INP_LP1_LEFT: C_LP_LEFT.1, FILTER_GAIN_STAGE_LEFT.3 (INA+), R_DUMMY_LEFT.2
POS_INP_LP1_RIGHT: C_LP_RIGHT.1, FILTER_GAIN_STAGE_RIGHT.3 (INA+), R_DUMMY_RIGHT.2
SIG_LEFT: R_DUMMY_LEFT_2.2, SIG_LEFT.1
SIG_RIGHT: R_DUMMY_RIGHT_2.2, SIG_RIGHT.1
VDD: C1.1, C3.1, FILTER_GAIN_STAGE_LEFT.8 (V+), FILTER_GAIN_STAGE_RIGHT.8 (V+), JP_SOURCE.1
VSS: C2.1, C4.1, FILTER_GAIN_STAGE_LEFT.4 (V-), FILTER_GAIN_STAGE_RIGHT.4 (V-), JP_SOURCE.3

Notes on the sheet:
pvdf board v3.1 designed by Uzun, the structure of the main board has changed. ADA4004-2 is used in place of OP97. The resistor and capacitance values have been changed. The gain resistors are not included inside the filter.


Board: 2 copper layers, 100.0 x 80.0 mm, 23 parts (1 on the bottom side), 15 nets.
